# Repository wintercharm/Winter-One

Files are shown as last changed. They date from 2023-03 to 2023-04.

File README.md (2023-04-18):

# Winter-One
Winter One SFFPC Case! Created by wintercharm & rayyanalam01

4ab4fb_02534cf7161d4a5695644483433a4a5b~mv2

## The New Cold Standard
Winter One was designed with the utmost care to deliver unprecedented cooling, whisper-quiet operation, and great hardware compatibility in a compact size.

## Small, Yet Mighty
At just 15.6 L, Winter One supports desktop-class components like dual 280 mm radiators, 3-slot graphics cards, and 70 mm CPU coolers.

### The Best Sandwich You'll Never Eat
Winter One uses the innovative Sandwich Layout, refined. We eliminated the central spine, improving airflow and freeing up internal volume for better flexibility.

### Flexibility At Your Fingertips
The frameless architecture of Winter One maximizes the interior volume. With ample room to route tubing, mount a pump, attach a drive cage, and add fans or radiators, you can build your dream system.

### Building in Winter One

#### Air Cooled Build Video

WinterCharm's Air Cooled Build (https://www.youtube.com/watch?v=ClOrqQxKIzM)

#### Water Cooled Build Video

Linus Tech Tips Review & Watercooling Build (https://www.youtube.com/watch?v=BoFxslm6DKY)

#### WinterCharm's Personal Build
[Small Winter Collider](https://pcpartpicker.com/b/QjBcCJ)

### Beauty Through Simplicity
The visually balanced exterior design conveys harmony and serenity, while the clean lines and anodized, bead-blasted aluminum command attention.

Double Case - Oblique 3

## Engineered to Perform
Thousands of hours of design and computational fluid dynamics have gone into crafting airflow through Winter One. Hello science, goodbye thermal throttling.

### It All Starts With CFD
The promise of Small Form Factor systems has always been putting desktop components into a small space. But the biggest drawback has always been thermals and noise. Until Now.

Screen Shot 2021-04-23 at 12_16_19 PM_pn

### Airflow Enhancements in Winter One
#### Reducing Flow Restriction across panels
Large holes provide low flow restriction, making it easier it is for air to cross from one side of the plate to the other, preventing stoppage of flow. This is especially important when it comes to passive cooling, where too much flow restriction can trap the heat within the case.

#### Linear Airflow Paths
For every 90º Turn made by flowing air, there is a loss in pressure and velocity. Winter One maintains linear airflow in the solid side panel configuration. With perforated side panels, the path air takes is limited to one 90º turn to provide each radiator with the necessary flow.

#### Acoustically Optimized Panels
Perforated Plate geometry, and distance from the plate to the fan blades has been carefully controlled, in order to create multiple, smaller transitions to turbulent flow, This spreads one acoustic peak into 3 separate peaks, creating a more pleasant noise profile to the human ear.

#### Eliminating Internal Surfaces
Surfaces that air flows against create boundary layer drag. Great care was taken to remove internal surfaces inside Winter One. Eliminating the central spine allows air to flow cleanly through the enclosure.

#### Backflow Barriers on the End-plates
When fan speeds are pushed higher, air had a tendency to loop around and re-circulate. The geometry of the inside of the end plate was altered, in order to provide a physical barrier to limit the backflow of air, further improving efficiency.

#### Optimized Foot Height
Many small form factor cases use the smallest possible feet to avoid adding volume. However, this drastically harms cooling, whether the case is set up for intake or exhaust at the bottom.

### Stunning Silence, By Design
The perfectly sized holes for airflow are also carefully acoustically optimized, lowering turbulence and noise during operation. The beautiful cork-padded feet provide additional vibration damping. Just like the airflow optimizations, our acoustic optimizations combined simulations with real-world testing to create an unbelievably silent system. At a 20cm measuring distance, with fans set to 1250 rpm, Winter One’s noise levels are incredible, at just 28 dBa. Everything above 1.2 KHz remains below 23dBa, barely noticeable.

## Specifications

Side Profile w Panel

### Dimensions and Weight

**Volume:** 15.6 L

**Enclosure Dimensions**
L: 32.2 cm (12.7 in)
W: 16.0 cm (6.3 in)
H: 30.2 cm (11.9 in)

**With Protrusions**
L: 32.5 cm (12.8 in)
W: 16.0 cm (6.3 in)
H: 32.2 cm (12.7 in)

**Materials:** Al 6061-T6 (Anodized + Bead Blasted), Cork
**Weight:** 1.9 kg (4.2 lb)

### Part Compatibility 
4ab4fb_482371a2333d489d930ea15a6e4dff3b~mv2

### User Manual
[Winter One Manual v12 rev9.pdf](https://github.com/wintercharm/Winter-One/files/11012925/Winter.One.Manual.v12.rev9.pdf)

## License 
<br />This work is licensed under a <a rel="license" href="http://creativecommons.org/licenses/by-nc/3.0/">Creative Commons Attribution-NonCommercial 3.0 Unported License</a>.

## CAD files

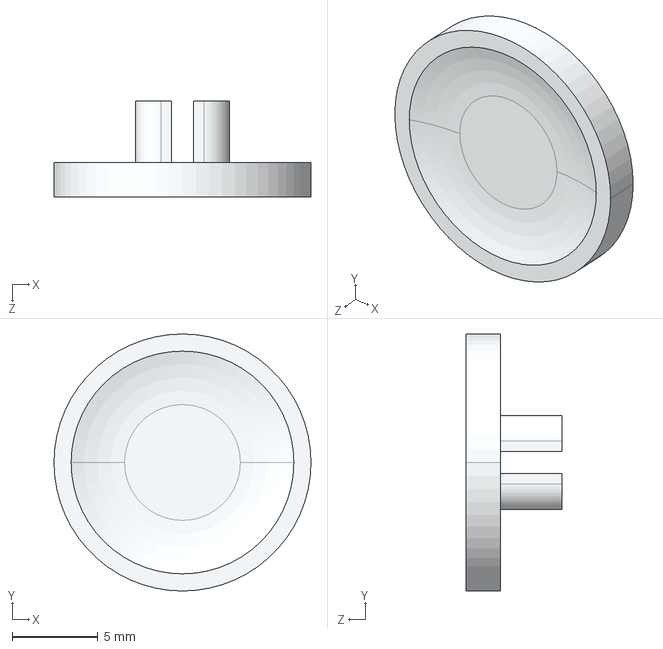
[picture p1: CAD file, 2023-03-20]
Winter One STEP v13/v12 Power Button.STEP
15.0 x 15.0 x 5.60 mm

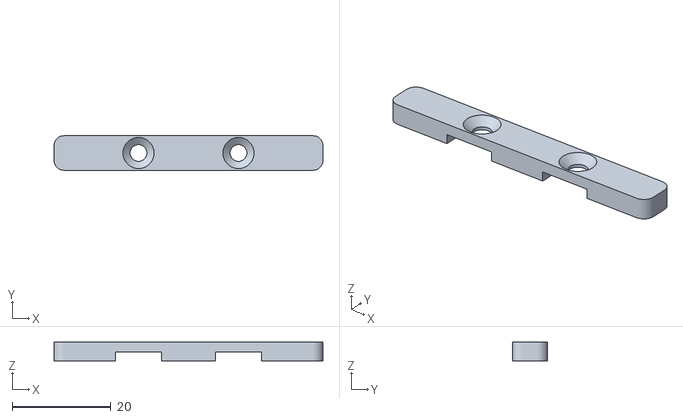
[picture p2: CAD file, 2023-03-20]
Winter One STL v13/v13 PCIE Clamp.STL
54.5 x 7.00 x 3.75

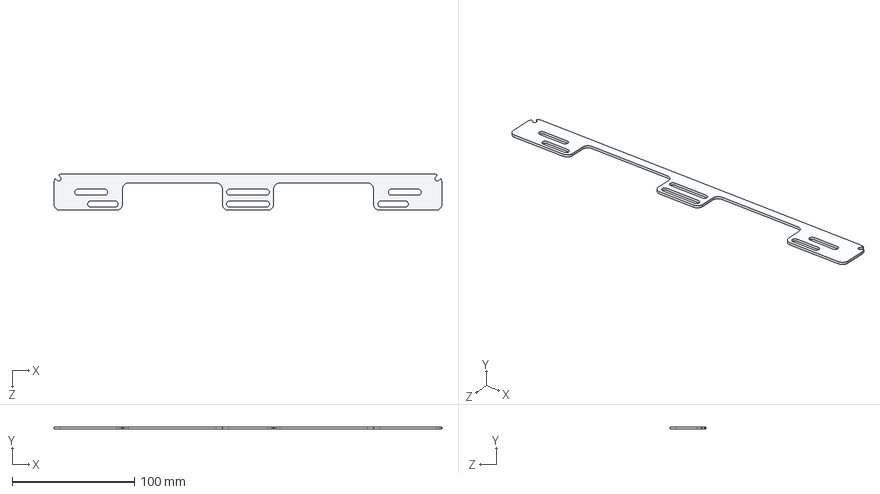
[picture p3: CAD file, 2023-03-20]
Winter One STEP v13/v12 Fan Strip.STEP
317.3 x 2.00 x 29.8 mm

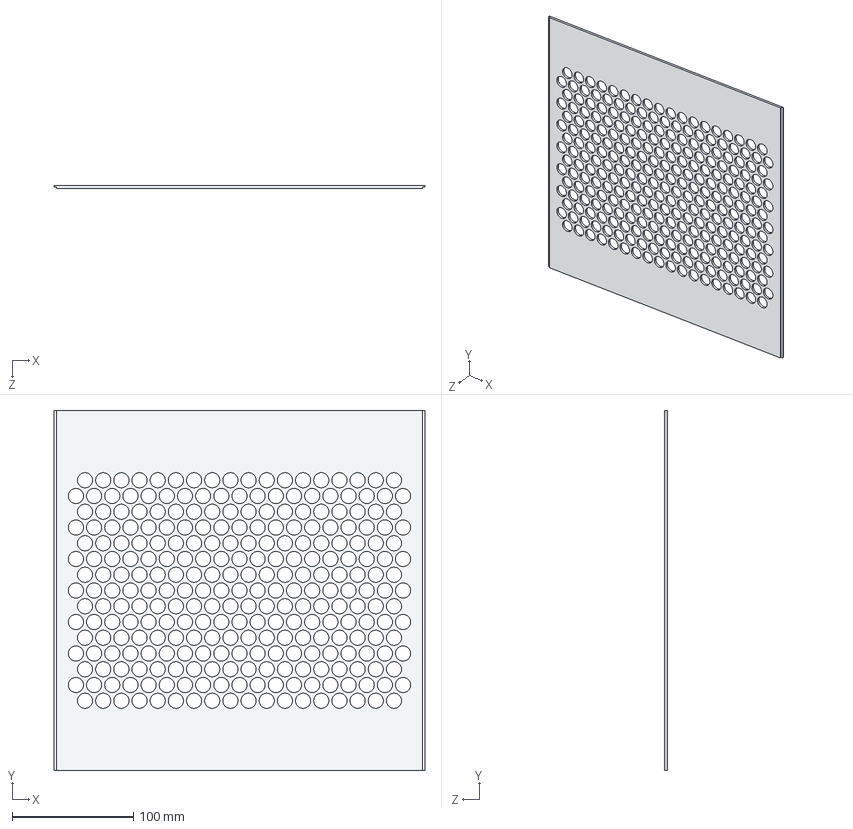
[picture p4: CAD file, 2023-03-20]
Winter One STEP v13/v12 Side Panel (Holes).STEP
306.2 x 297.5 x 2.50 mm

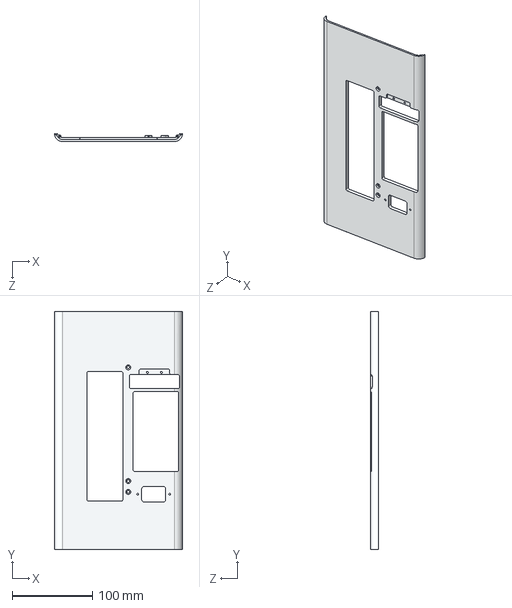
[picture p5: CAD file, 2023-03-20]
Winter One STEP v13/v13b Rear Panel.STEP
160.0 x 297.5 x 10.0 mm

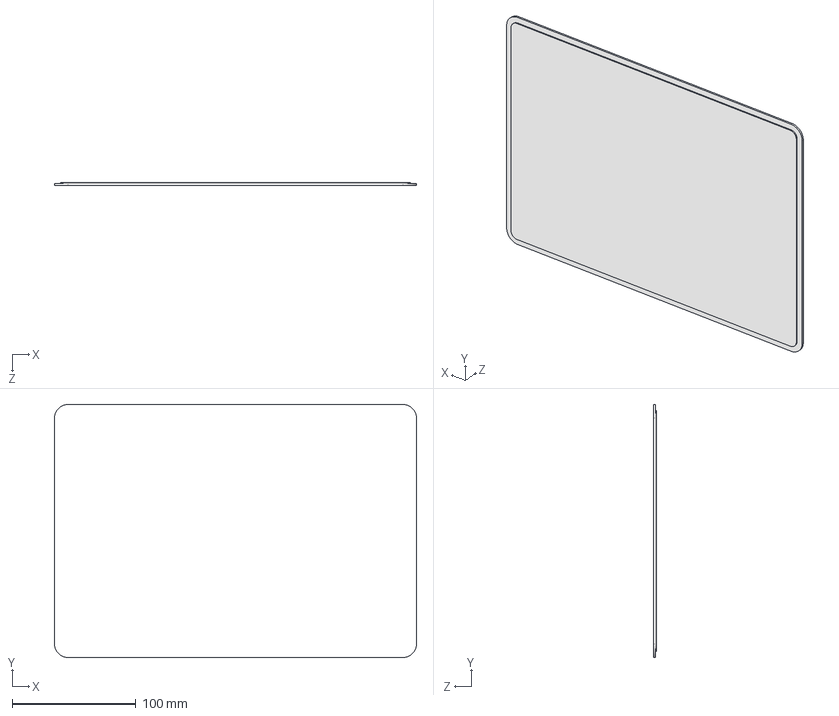
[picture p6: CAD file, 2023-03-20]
Winter One STEP v13/v13 Acrylic Window.STEP
292.3 x 204.3 x 2.50 mm

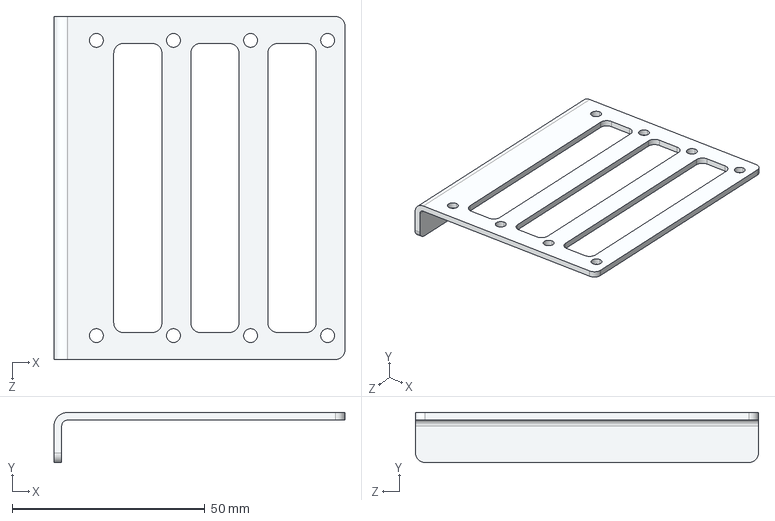
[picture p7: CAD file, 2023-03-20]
Winter One STEP v13/v13 Drive Cage Lower.STEP
75.5 x 13.0 x 89.0 mm

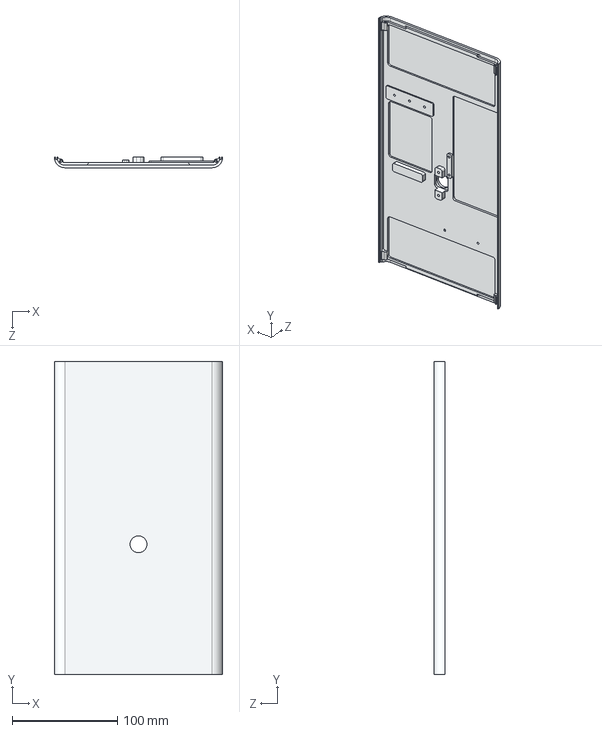
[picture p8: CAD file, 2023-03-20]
Winter One STEP v13/v13 Front Panel.STEP
160.0 x 297.5 x 10.0 mm

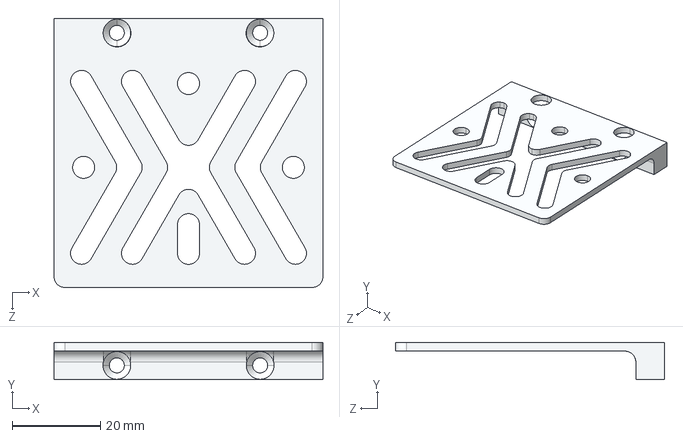
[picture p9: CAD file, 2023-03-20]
Winter One STEP v13/v13 Pump Bracket.STEP
61.0 x 8.50 x 61.0 mm

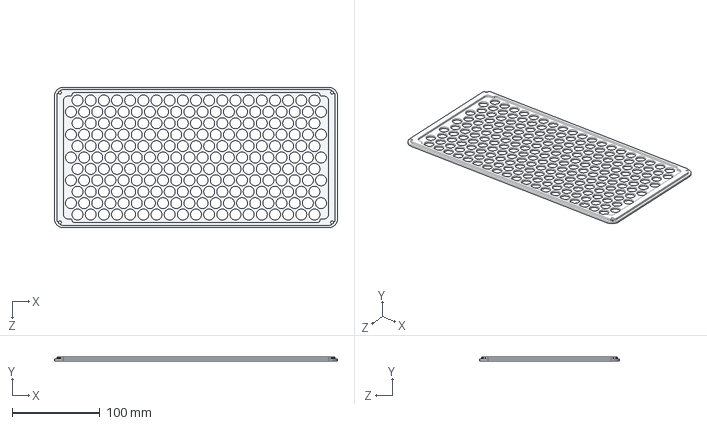
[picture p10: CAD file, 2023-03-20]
Winter One STEP v13/v12 End Plate.STEP
322.5 x 5.00 x 160.0 mm

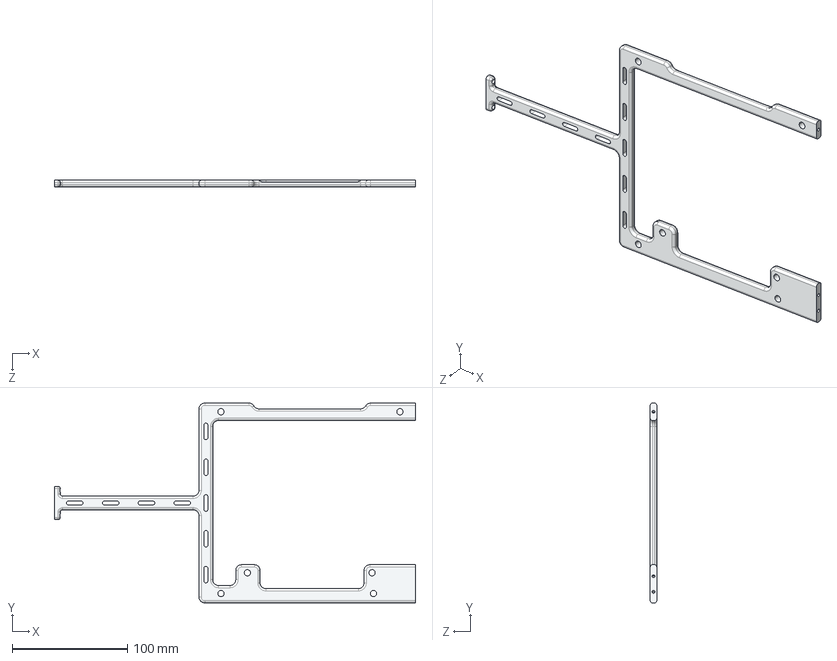
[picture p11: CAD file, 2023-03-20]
Winter One STEP v13/v13 Central Spine.STEP
312.6 x 173.1 x 5.65 mm

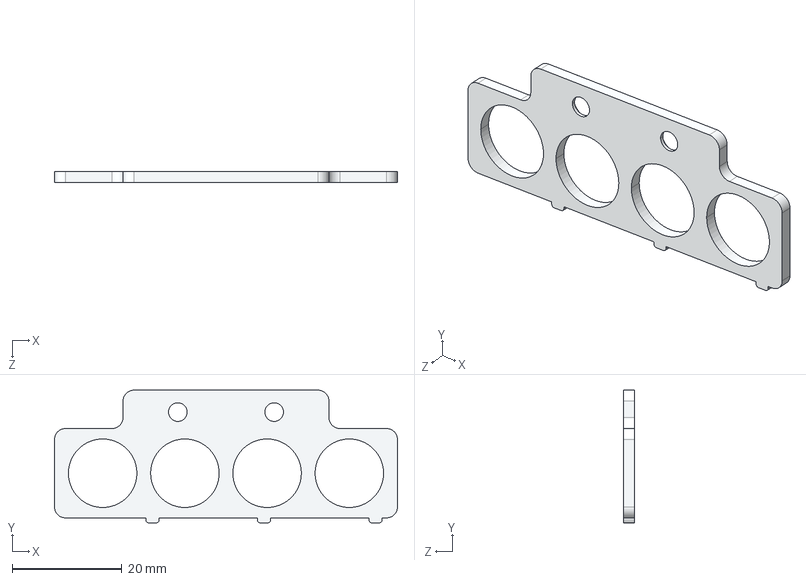
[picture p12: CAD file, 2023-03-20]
Winter One STEP v13/v13 GPU Holder.STEP
62.6 x 24.2 x 2.00 mm

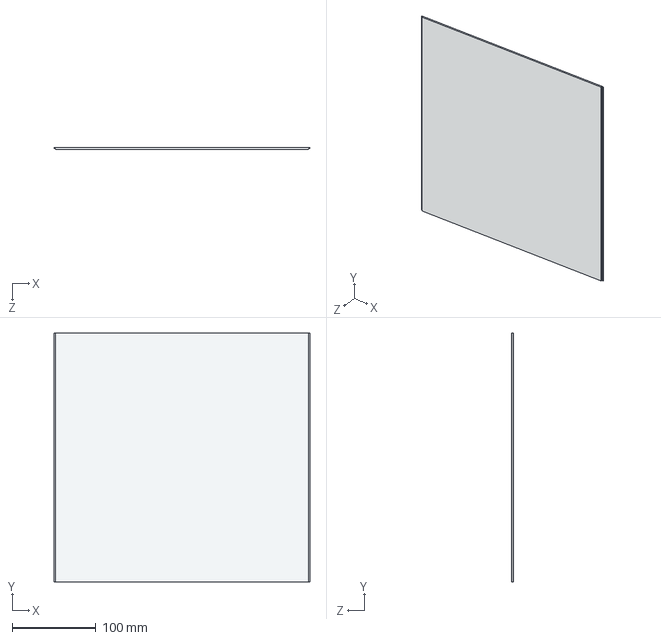
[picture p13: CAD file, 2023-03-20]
Winter One STEP v13/v12 Side Panel (Solid).STEP
306.2 x 297.5 x 2.50 mm

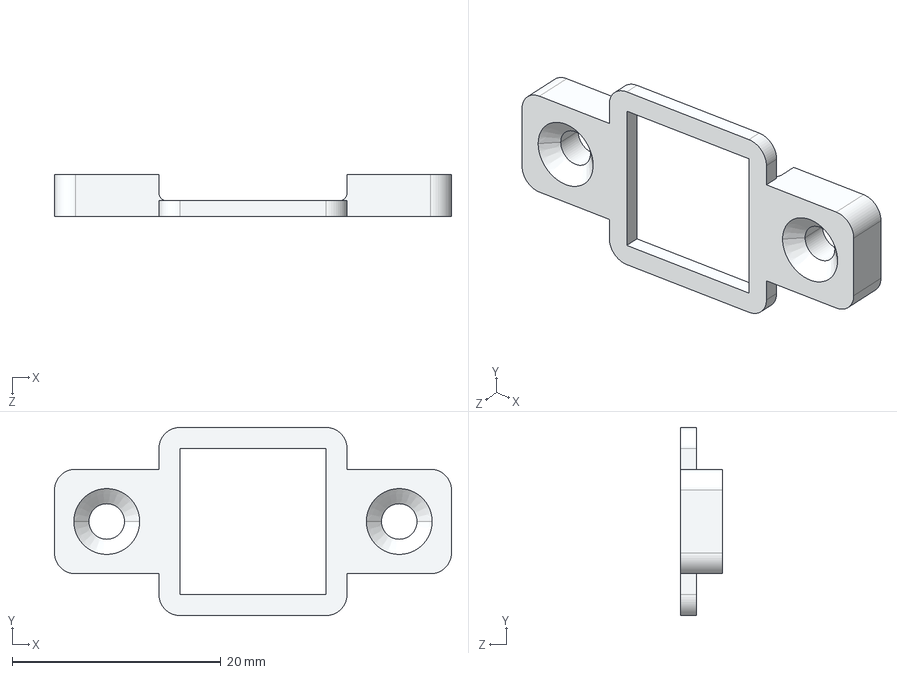
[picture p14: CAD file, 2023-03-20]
Winter One STEP v13/v13 Power Button Bracket.STEP
38.0 x 18.0 x 4.00 mm

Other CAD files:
Winter One STEP v13/v12 Foot.STEP
Winter One STEP v13/v13 PCIE Cover.STEP
Winter One STEP v13/v13 Drive Cage Upper.STEP
Winter One STEP v13/v13 Side Panel Window.STEP
Winter One STEP v13/v12 Foot Washer.STEP
Winter One STEP v13/v12 PSU Bracket.STEP
Winter One STEP v13/v12 Pump Bracket.STEP
Winter One STEP v13/v13 Foot Washer.STEP
Winter One STL v13/v13 Drive Cage Lower.STL
Winter One STL v13/v13 Drive Cage Upper.STL
Winter One STL v13/v13 Foot Washer.STL
Winter One STL v13/v13 Power Button Bracket.STL

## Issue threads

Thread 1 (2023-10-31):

Gpu Custom Cable Lengths are incorrect

wintercharm, 2023-10-31:
GPU Custom Cable Lengths are INCORRECT --- Should be 300mm and 320mm (NOT 200mm + 220mm) --- page 04 of user manual.

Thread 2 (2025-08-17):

Thread specifications

infrd, 2025-08-17:
Hi,
Not sure if I'm mistaken but I don't see any threads for the screws in the step files or specifications listed anywhere. I also don't see any information regarding the stand offs for central spine. Any information is appreciated. Apologies if I am mistaken. Thanks.

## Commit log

2023-03-19 Winter One v13 cad files
    ALL STLs are in units of mm
    [v12 End Plate.STEP, v12 Fan Strip.STEP, v12 Foot Washer.STEP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]
2023-03-20 Final CAD updates
    Finalized cad updates and ensured all files are available.
    [v12 End Plate.STEP, v12 Fan Strip.STEP, v12 Foot Washer.STEP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]
